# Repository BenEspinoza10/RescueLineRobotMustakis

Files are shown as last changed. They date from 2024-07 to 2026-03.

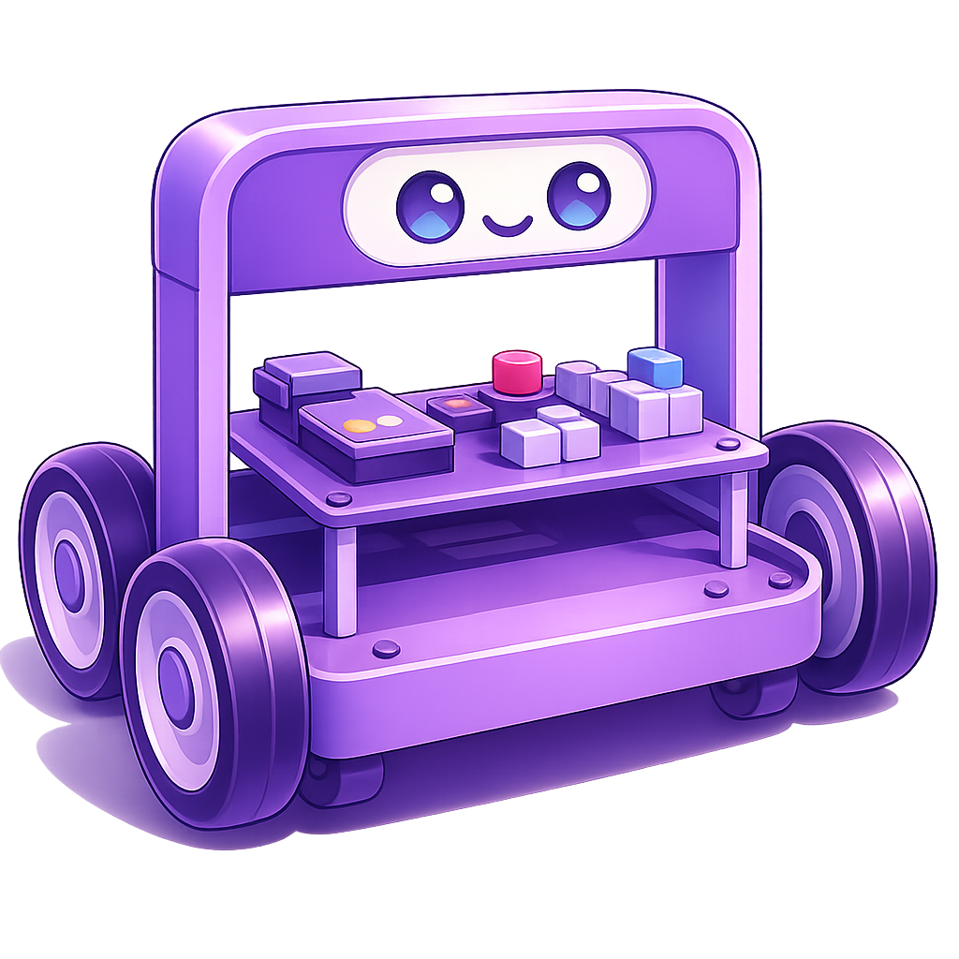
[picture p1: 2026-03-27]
misc/ChatGPT Image 10 mar 2026, 04_27_27 p.m..png

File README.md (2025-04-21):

# Club Robótica Linea Rescue Line
Este es el repositorio de la línea de robótica Rescue Line Aquí encontrás todo lo necesario para ejecutar las sesiones de manera exitosa.

## Sesiones
- Las presentaciones PPT por sesión se pueden encontrar en el siguiente link: [Presentaciones](https://docs.google.com/presentation/d/1HhJf0Knq2RezBDOXF99ei00qkOhWetyh1tN6ezIQvbw/edit?usp=drive_link)

## Archivos de construcción
En la carpeta archivos de construcción se pueden encontrar los modelos 3D, svg y el Gerber de Dynamis

En caso de ser necesario, dentro de la carpeta RescueLineRobot, se encuentra el proyecto original en KiCad. Este contienen los esquemáticos de los circuitos y el diseño de la pcb. 

## Errores y sugerencia

En caso de que se encuentren errores de contenido y/o cualquier otro problema relacionado a las sesiones, por favor añadirlo como una Issue al repositorio, de esta manera se queda registro de los cambios realizados historicamente para futuras referencias en un único lugar.

---
*Trabajo realizado por Benjamin Espinoza para el programa de Ciencia y Tecnología de la Fundación Mustakis, 2024*

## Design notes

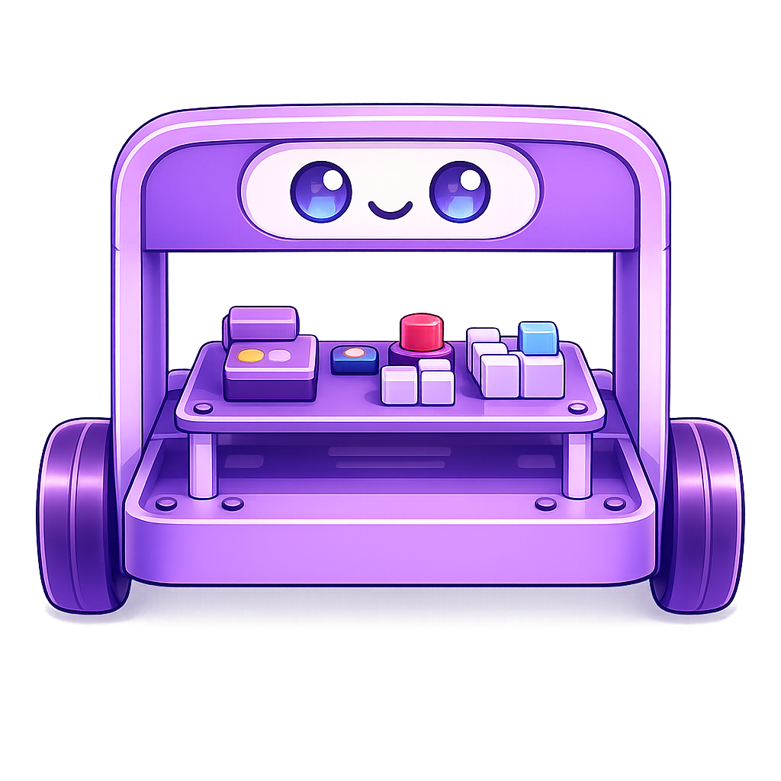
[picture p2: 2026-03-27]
misc/ChatGPT Image 10 mar 2026, 04_49_32 p.m..png

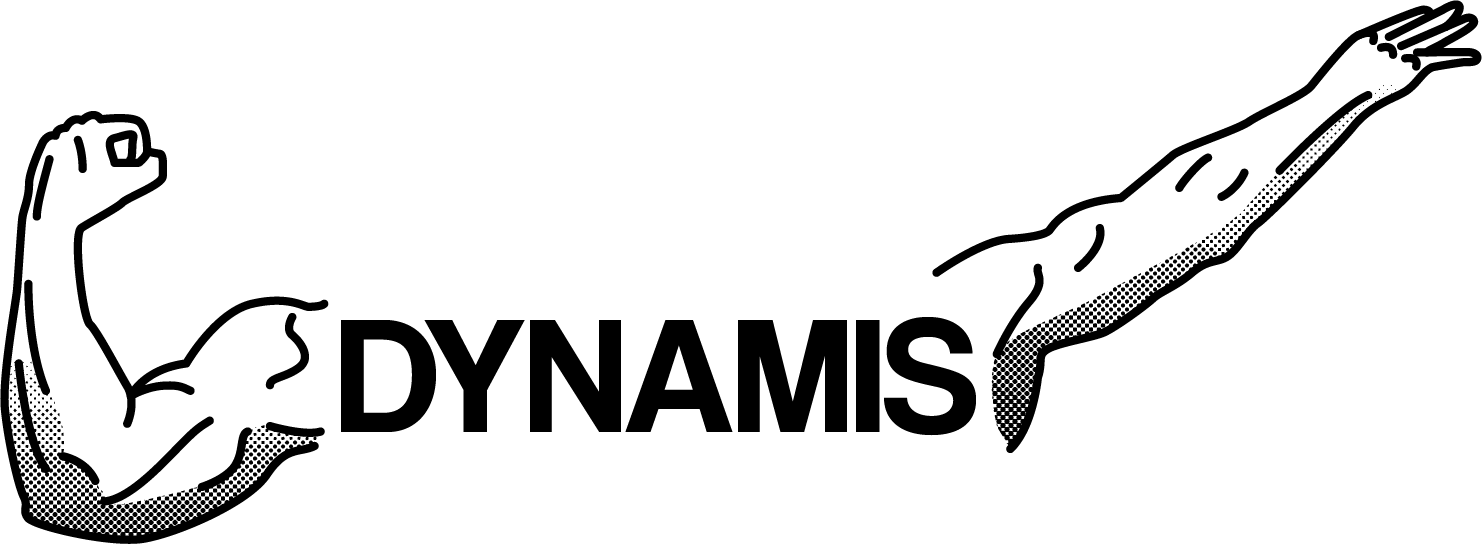
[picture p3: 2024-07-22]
misc/DyNaMis2.png

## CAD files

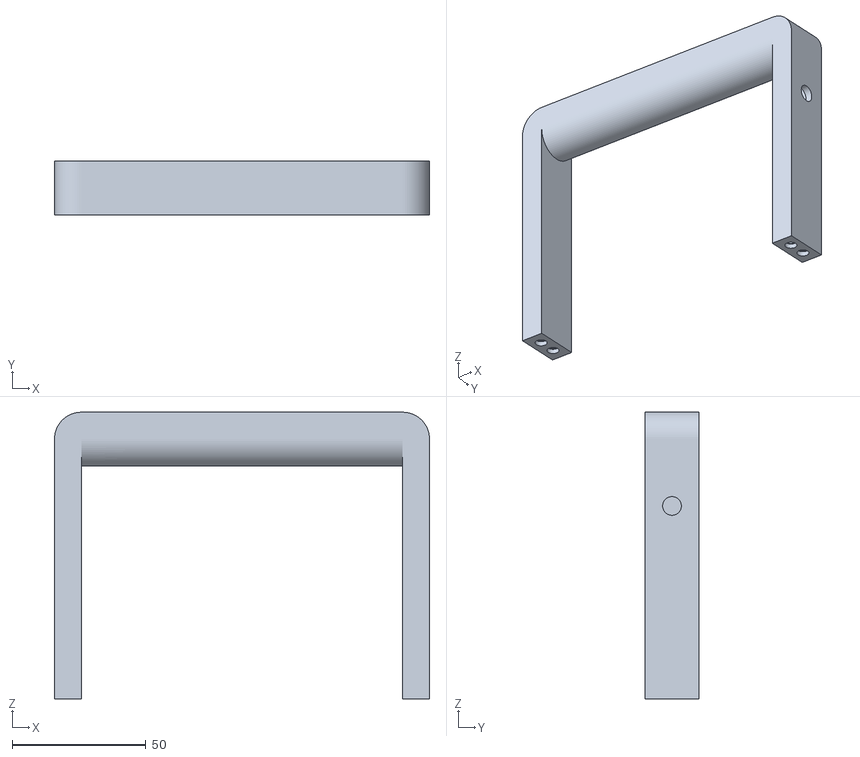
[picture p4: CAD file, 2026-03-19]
Archivos de construccion/V1.1/ManillaV2.stl
140.0 x 20.0 x 107.0

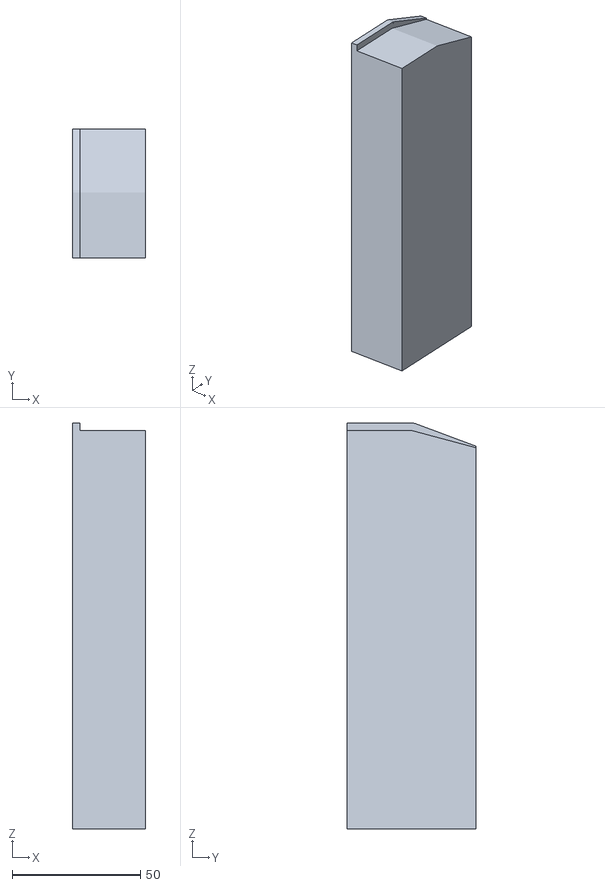
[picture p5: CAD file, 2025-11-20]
ArchivosRampa15grados60cm/PilarB.stl
28.4 x 50.1 x 158.0

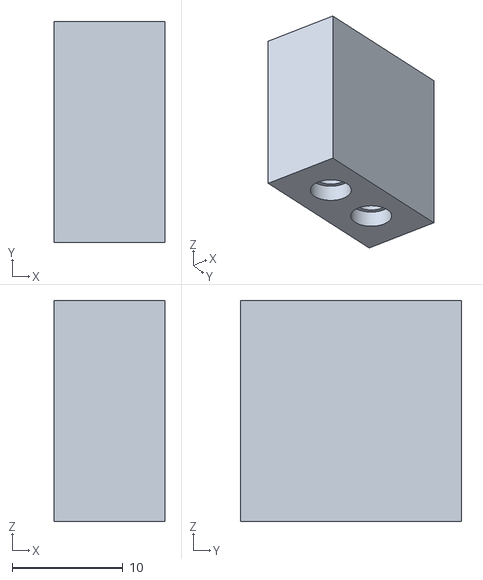
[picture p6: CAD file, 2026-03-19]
Archivos de construccion/V1.1/ManillaTEST.stl
10.0 x 20.0 x 20.0

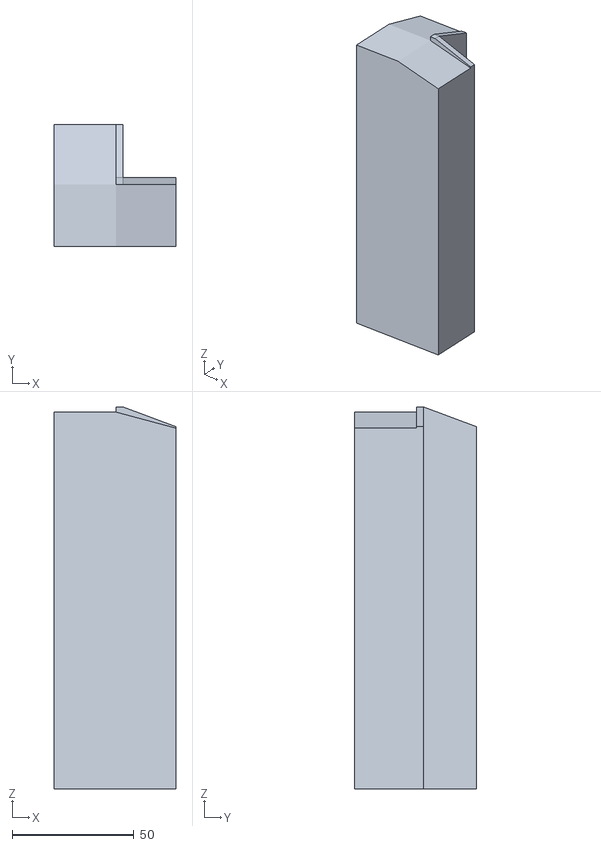
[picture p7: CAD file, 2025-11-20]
ArchivosRampa15grados60cm/PilarEsquinaInterna.stl
50.1 x 50.1 x 157.1

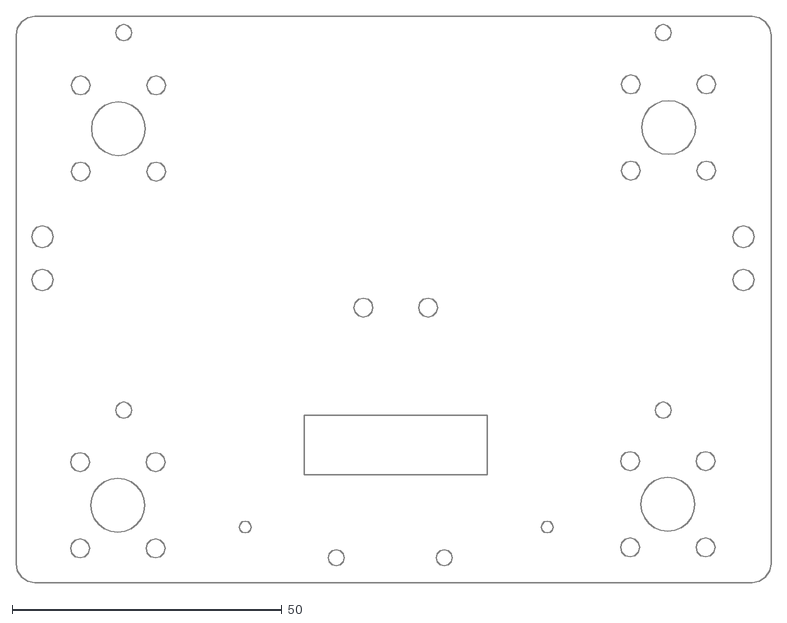
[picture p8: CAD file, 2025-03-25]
Archivos de construccion/V1.1/BaseDynamisV2.1.dxf
140.0 x 105.0

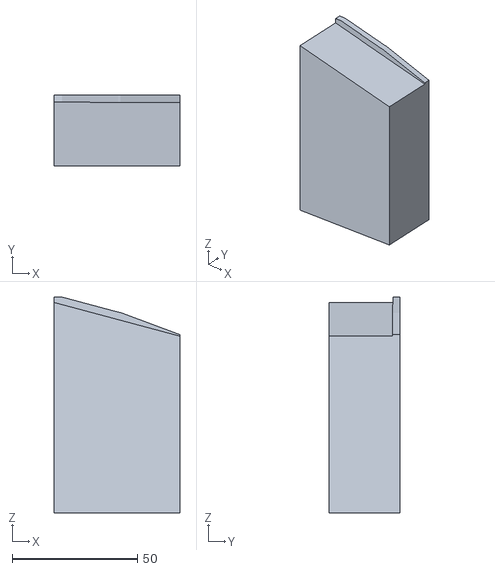
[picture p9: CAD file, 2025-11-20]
ArchivosRampa15grados60cm/Pilar IntermedioB.stl
50.1 x 28.4 x 86.1

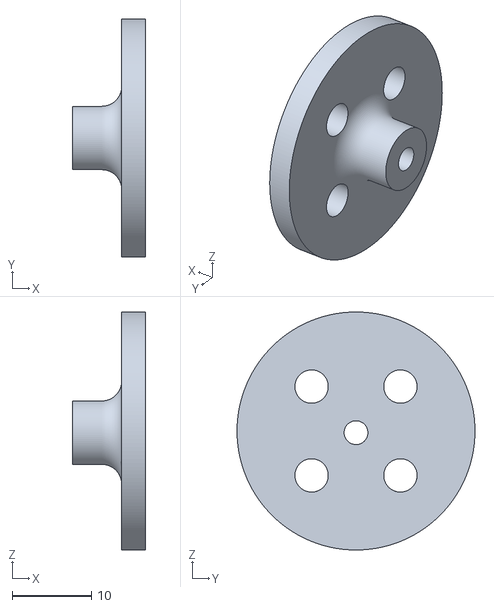
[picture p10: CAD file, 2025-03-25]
Archivos de construccion/V1.1/Enganche Rueda Rodamiento.stl
9.19 x 30.0 x 30.0

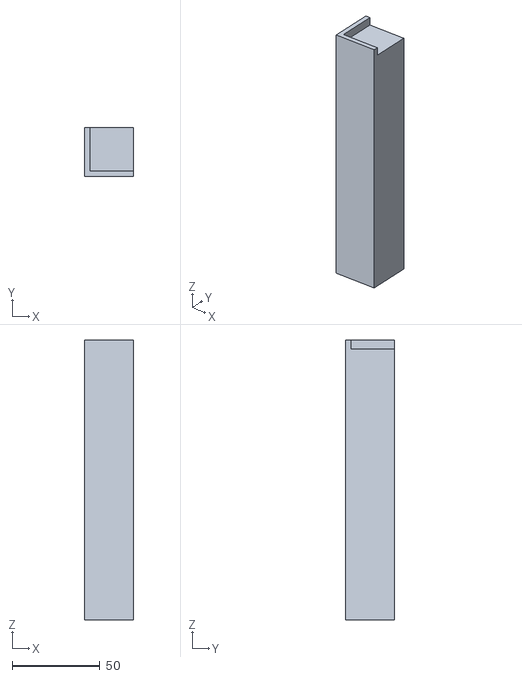
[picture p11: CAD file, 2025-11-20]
ArchivosRampa15grados60cm/PilarEsquinaExterna.stl
28.0 x 28.0 x 160.0

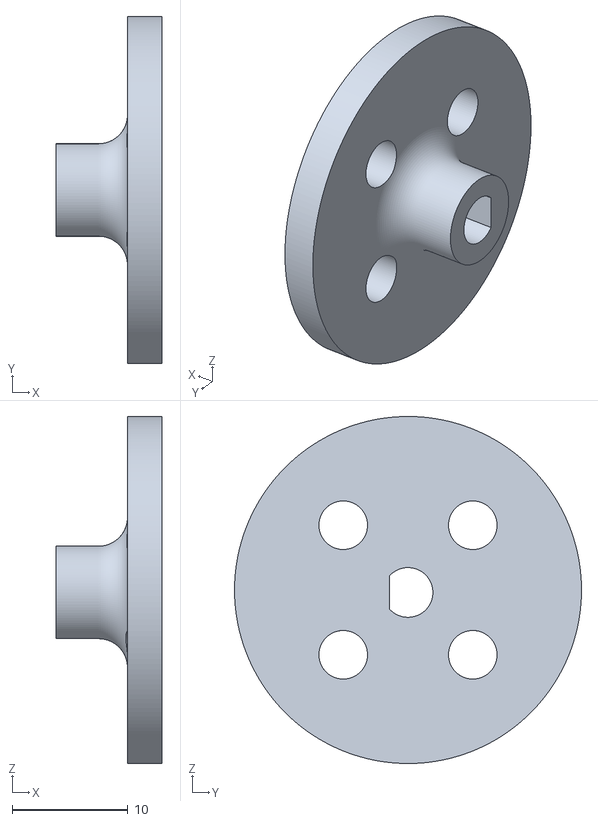
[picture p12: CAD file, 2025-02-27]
Archivos de construccion/V1.1/Enganche Rueda.stl
9.19 x 30.0 x 30.0

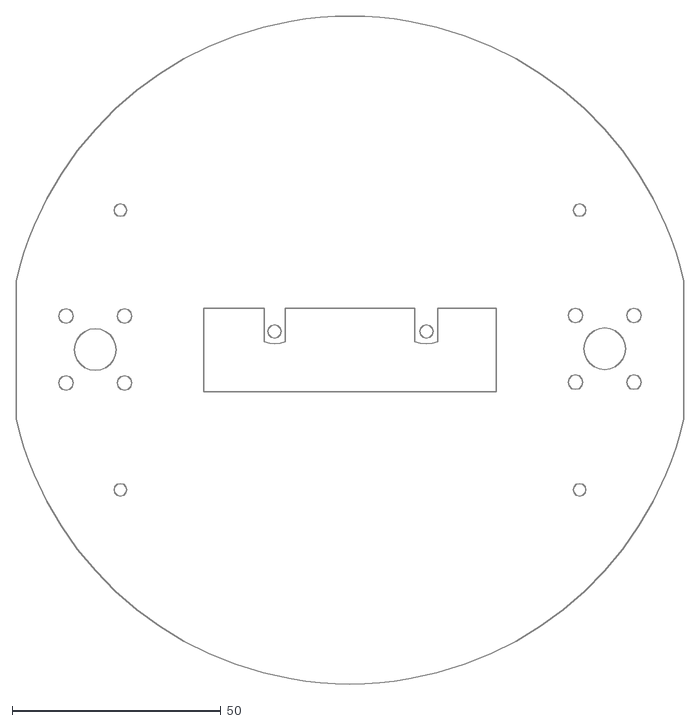
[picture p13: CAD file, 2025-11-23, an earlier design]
Archivos de construccion/V1/Robot Rescue Line/Base RescueLineRobot.dxf
160.0 x 160.0

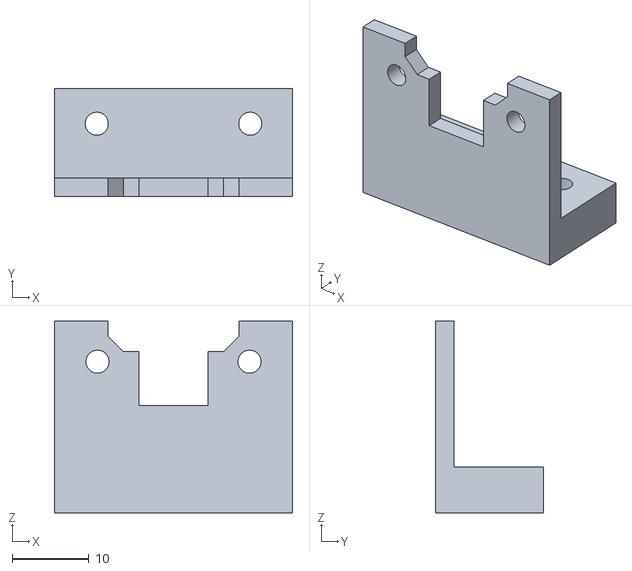
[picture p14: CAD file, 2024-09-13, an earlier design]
Archivos de construccion/V1/Soporte Láser Chico.stl
31.0 x 14.1 x 25.0

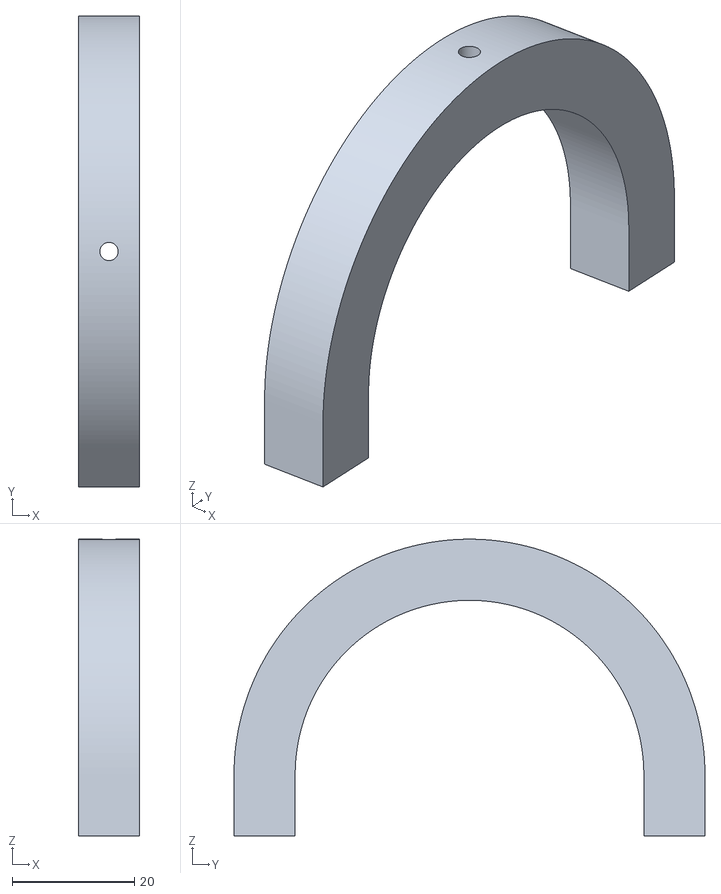
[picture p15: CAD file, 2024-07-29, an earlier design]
Archivos de construccion/V1/Robot Rescue Line/Base Handle.stl
10.0 x 77.0 x 48.5

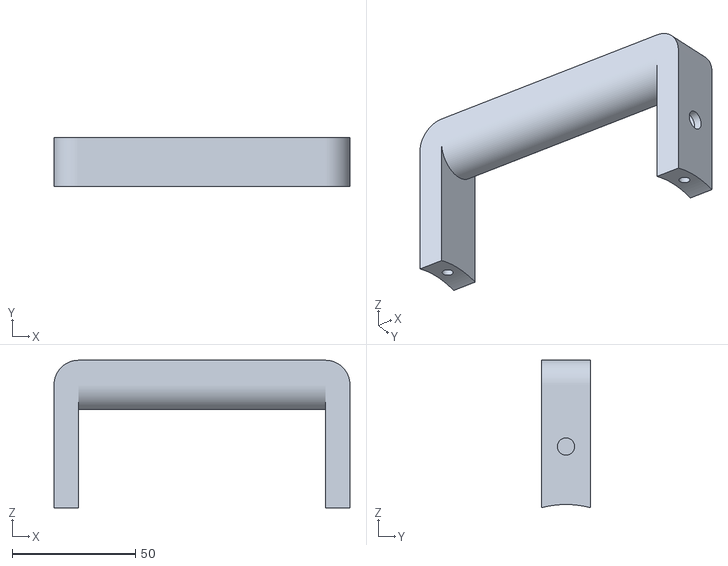
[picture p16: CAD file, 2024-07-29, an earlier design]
Archivos de construccion/V1/Robot Rescue Line/Handle.stl
120.0 x 20.0 x 59.8

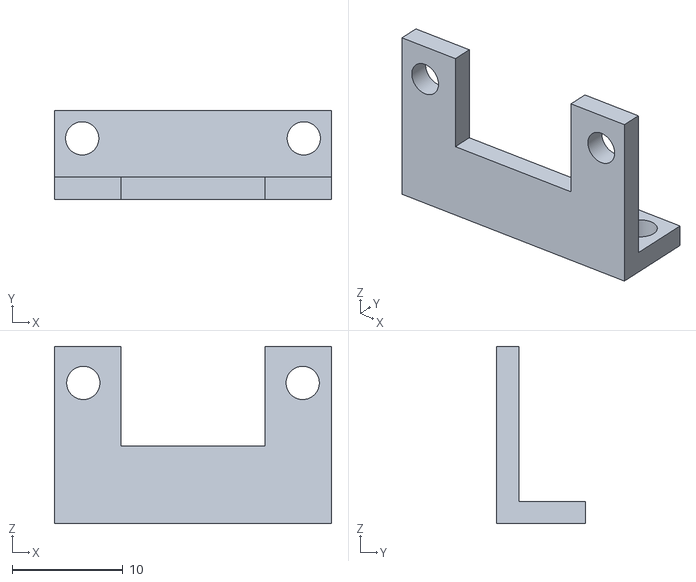
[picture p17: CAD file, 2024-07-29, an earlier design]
Archivos de construccion/V1/Robot Rescue Line/Soporte Láser.stl
25.0 x 8.00 x 16.0

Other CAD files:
ArchivosRampa15grados60cm/PilarA.stl
ArchivosRampa15grados60cm/Pilar IntermedioA.stl
Archivos de construccion/V1.1/Manilla.stl
Archivos de construccion/V1.1/BaseDynamisV2.dxf
Archivos de construccion/V1.1/RescueLineRobot.f3z
Fusion360/RescueLineRobot.f3z

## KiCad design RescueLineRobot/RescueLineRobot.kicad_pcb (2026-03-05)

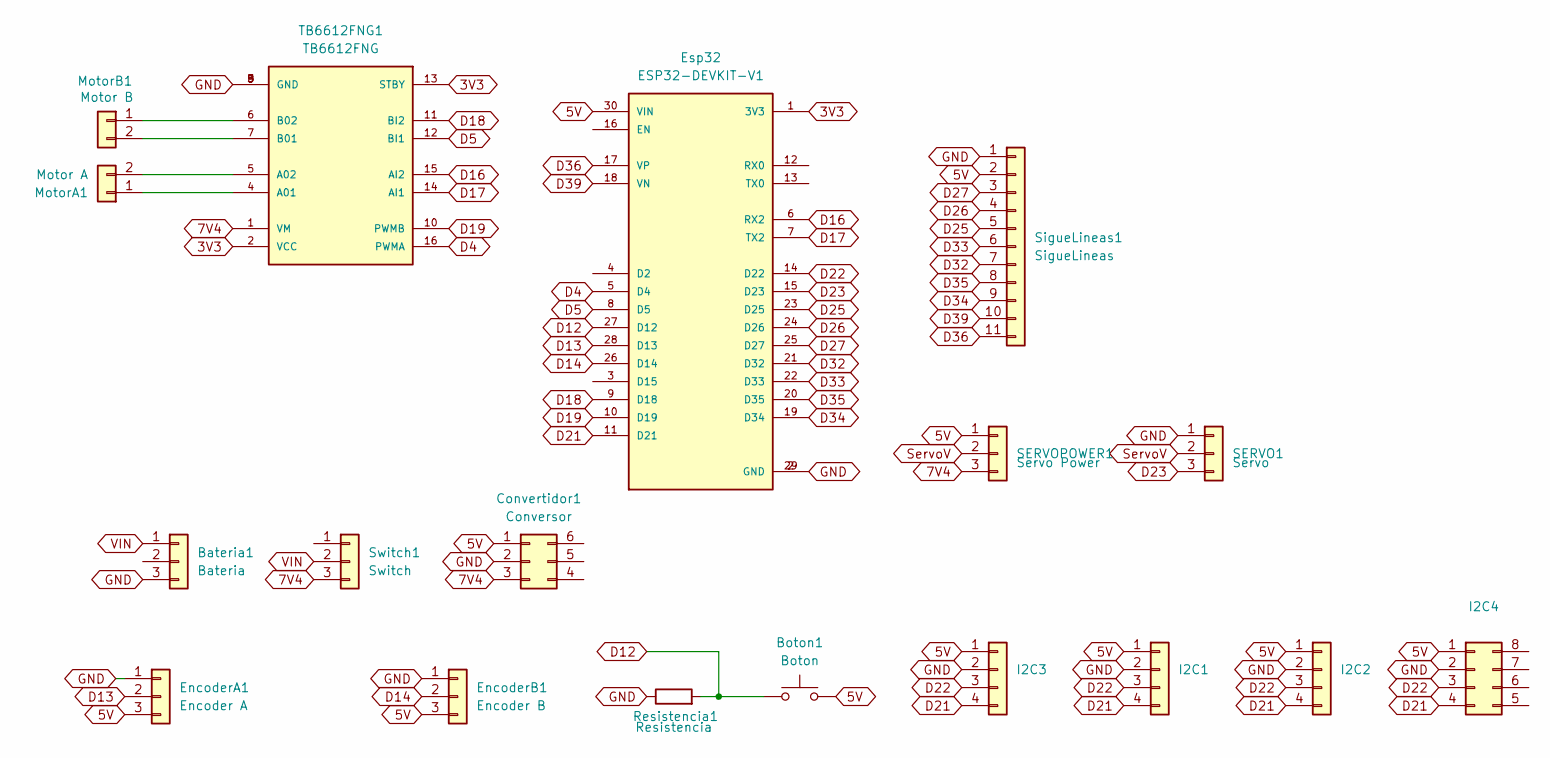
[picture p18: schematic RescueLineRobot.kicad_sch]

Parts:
Bateria1: Bateria; JST_XH_B3B-XH-A_1x03_P2.50mm_Vertical
Boton1: Boton; SW_PUSH-12mm
Convertidor1: Conversor; PinHeader_2x03_P2.54mm_Vertical
EncoderA1: Encoder A; JST_XA_B03B-XASK-1_1x03_P2.50mm_Vertical
EncoderB1: Encoder B; JST_XA_B03B-XASK-1_1x03_P2.50mm_Vertical
Esp32: ESP32-DEVKIT-V1; MODULE_ESP32_DEVKIT_V1; PARTREV N/A
I2C1, I2C2, I2C3, I2C4: JST_XH_B4B-XH-A_1x04_P2.50mm_Vertical
MotorA1: Motor A; JST_XH_B2B-XH-A_1x02_P2.50mm_Vertical
MotorB1: Motor B; JST_XH_B2B-XH-A_1x02_P2.50mm_Vertical
Resistencia1: Resistencia; R_Axial_DIN0617_L17.0mm_D6.0mm_P25.40mm_Horizontal
SERVO1: Servo; JST_XH_B3B-XH-A_1x03_P2.50mm_Vertical
SERVOPOWER1: Servo Power; PinHeader_1x03_P2.54mm_Vertical
SigueLineas1: SigueLineas; JST_XH_B11B-XH-A_1x11_P2.50mm_Vertical
Switch1: Switch; JST_XH_B3B-XH-A_1x03_P2.50mm_Vertical
TB6612FNG1: TB6612FNG; MODULE_ROB-14450; PARTREV 11-13-17

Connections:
3V3: Esp32.1 (3V3), TB6612FNG1.2 (VCC), TB6612FNG1.13 (STBY)
5V: Boton1.2, Convertidor1.1, EncoderA1.3, EncoderB1.3, Esp32.30 (VIN), I2C1.1, I2C2.1, I2C3.1, I2C4.1, SERVOPOWER1.1, SigueLineas1.2
7V4: Convertidor1.3, SERVOPOWER1.3, Switch1.3, TB6612FNG1.1 (VM)
D4: Esp32.5 (D4), TB6612FNG1.16 (PWMA)
D5: Esp32.8 (D5), TB6612FNG1.12 (BI1)
D12: Boton1.1, Esp32.27 (D12), Resistencia1.2
D13: EncoderA1.2, Esp32.28 (D13)
D14: EncoderB1.2, Esp32.26 (D14)
D16: Esp32.6 (RX2), TB6612FNG1.15 (AI2)
D17: Esp32.7 (TX2), TB6612FNG1.14 (AI1)
D18: Esp32.9 (D18), TB6612FNG1.11 (BI2)
D19: Esp32.10 (D19), TB6612FNG1.10 (PWMB)
D21: Esp32.11 (D21), I2C1.4, I2C2.4, I2C3.4, I2C4.4
D22: Esp32.14 (D22), I2C1.3, I2C2.3, I2C3.3, I2C4.3
D23: Esp32.15 (D23), SERVO1.3
D25: Esp32.23 (D25), SigueLineas1.5
D26: Esp32.24 (D26), SigueLineas1.4
D27: Esp32.25 (D27), SigueLineas1.3
D32: Esp32.21 (D32), SigueLineas1.7
D33: Esp32.22 (D33), SigueLineas1.6
D34: Esp32.19 (D34), SigueLineas1.9
D35: Esp32.20 (D35), SigueLineas1.8
D36: Esp32.17 (VP), SigueLineas1.11
D39: Esp32.18 (VN), SigueLineas1.10
GND: Bateria1.3, Convertidor1.2, EncoderA1.1, EncoderB1.1, Esp32.2 (GND), Esp32.29 (GND), I2C1.2, I2C2.2, I2C3.2, I2C4.2, Resistencia1.1, SERVO1.1, SigueLineas1.1, TB6612FNG1.3 (GND), TB6612FNG1.8 (GND), TB6612FNG1.9 (GND)
unnamed: MotorA1.1, TB6612FNG1.4 (A01)
unnamed: MotorA1.2, TB6612FNG1.5 (A02)
unnamed: MotorB1.1, TB6612FNG1.6 (B02)
unnamed: MotorB1.2, TB6612FNG1.7 (B01)
ServoV: SERVO1.2, SERVOPOWER1.2
VIN: Bateria1.1, Switch1.2

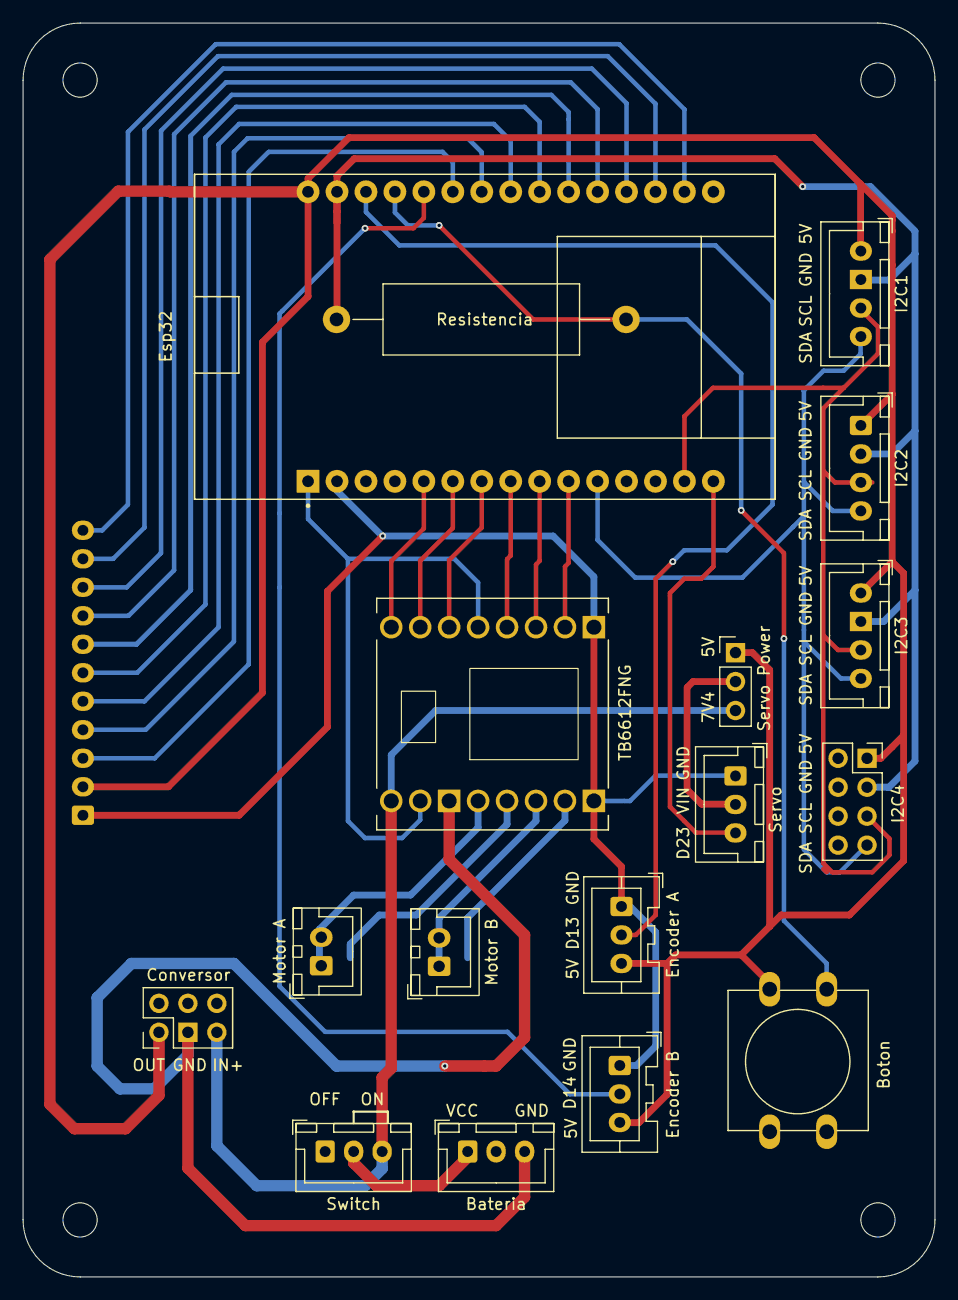
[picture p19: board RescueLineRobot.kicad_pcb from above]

Board: 2 copper layers, 80.0 x 110.0 mm, 18 parts (1 on the bottom side), 31 nets.

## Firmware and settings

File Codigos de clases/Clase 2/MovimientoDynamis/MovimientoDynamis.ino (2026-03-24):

//Se incluyen los pines
#include "Pines.h"

//Se define la frecuencia y resolución
//Se puede jugar con la frecuencie entre 5000 y 8000, no vale la pena tocar la resolución
const int freq = 5000;
const int resolution = 8;


void setup() {
  // Se inicializa los motores
  inicializarMotores();
  //Se espera a que se presione el botón para empezar
  while (digitalRead(BOTON) == 0) {
  }
}

void loop() {
  //Una serie de movimientos para probar las diferentes capacidades de la funcion
  Motor(150,150);
  delay(1000);
  Motor(-150,150);
  delay(1000);
  Motor(0,0);
  delay(1000);
  Motor(150,-150);
  delay(1000);
}

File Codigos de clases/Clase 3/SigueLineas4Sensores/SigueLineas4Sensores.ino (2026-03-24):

#include "Pines.h"
//Librería para el sensor IR
#include <QTRSensors.h>

const int freq = 5000;
const int resolution = 8;

//Se crea el objeto del qtr
QTRSensors qtr;

//Se crea el arreglo para almacenar las lectura
const uint8_t SensorCount = 8;
uint16_t sensorValues[SensorCount];

//Se definen umbrales para cada sensor (valores arbitrarios, en la practica se debe ajustar)
int umbrales[SensorCount] = {3000,3000,3000,3000,3000,3000,3000,3000};

void setup() {
  inicializarMotores();
  inicializarSensores();
  while (digitalRead(BOTON) == 0) {
  }
}

void loop() {
  //Se actualiza la lectura del sensor
  qtr.read(sensorValues);
  //Se hace un siguelíneas simple con máquina de estados
  //B,B,B,B
  if (sensorValues[2] < umbrales[2] and sensorValues[3] < umbrales[3] and sensorValues[4] < umbrales[4] and sensorValues[5] < umbrales[5]){
    Motor(0,0);
  //B,N,N,B
  } else if (sensorValues[2] < umbrales[2] and sensorValues[3] >= umbrales[3] and sensorValues[4] >= umbrales[4] and sensorValues[5] < umbrales[5]){
    Motor(50,50);
  //N,N,B,B
  } else if (sensorValues[2] >= umbrales[2] and sensorValues[3] >= umbrales[3] and sensorValues[4] < umbrales[4] and sensorValues[5] < umbrales[5]){
    Motor(50,100);
  //B,B,N,N
  } else if (sensorValues[2] < umbrales[2] and sensorValues[3] < umbrales[3] and sensorValues[4] >= umbrales[4] and sensorValues[5] >= umbrales[5]){
    Motor(100,50);
  }
}

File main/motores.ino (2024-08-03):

#include"definiciones.h"
void setupMotores(){
  //configuracion motores
  pinMode(BIN2  , OUTPUT);
  pinMode(BIN1  , OUTPUT);
  ledcSetup(1, freq, resolution);
  ledcAttachPin(PWMB, 1);
  pinMode(AIN1  , OUTPUT);
  pinMode(AIN2  , OUTPUT);
  ledcSetup(0, freq, resolution);
  ledcAttachPin(PWMA, 0);
}


void Motoriz(int value) {
  if ( value >= 0 ) {
    digitalWrite(BIN1, LOW);
    digitalWrite(BIN2, HIGH);
  } else {
    digitalWrite(BIN1, HIGH);
    digitalWrite(BIN2, LOW);
    value *= -1;
  }
  ledcWrite(0, value);
}
// Función accionamiento motor derecho
void Motorde(int value) {
  if ( value >= 0 ) {
    digitalWrite(AIN1, HIGH);
    digitalWrite(AIN2, LOW);
  } else {
    digitalWrite(AIN1, LOW);
    digitalWrite(AIN2, HIGH);
    value *= -1;
  }
  ledcWrite(1, value);
}

//Accionamiento de motores
void mover(int left, int righ) {
  Motoriz(left);
  Motorde(righ);
}

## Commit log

2024-03-12 Sensor y motores
    Se ajustó cableado de puente h y sensores para que quede mas simple la pcb, el sensor funciona con un código sucio xd
2024-03-12 Motores funcionan :D
    [RescueLineRobot.kicad_pcb, RescueLineRobot.kicad_sch]
2024-03-13 Actualizacion de pcb
    Ahora la pcb está más limpia y con serigrafía
    Pendientes:
    -2 Sensores RGB
    -1 Botón pulsador
    -2 Encoders para los motores (aun no se si cuadraticos o no)
    -1 Puerto para servo (maybe con selector de voltaje)
    [RescueLineRobot.kicad_pcb, RescueLineRobot.kicad_sch]
2024-03-13 Boton y encoders
    [RescueLineRobot.kicad_pcb, RescueLineRobot.kicad_sch]
2024-03-14 Estamos Casi
    Están todas las rutas hechas, todos los puertos necesarios, sólo falta nombrar al robot y poner gráficas
    [RescueLineRobot.kicad_pcb, RescueLineRobot.kicad_sch]
2024-03-14 logo update
    [RescueLineRobot.kicad_pcb]
2024-03-18 Dynamis a nacido
    Estamos listos señores!!!
    [RescueLineRobot.kicad_pcb, RescueLineRobot.kicad_sch]
2024-04-06 Arreglo de dirección
2024-04-09 Create pruebaBoton.ino
    Se creo el archivo para probar el boton
2024-04-11 ni idea que sea esto xd
    [RescueLineRobot.kicad_pcb]
2024-07-29 Arreglo sensores
2024-07-29 preparacion final
    [Base Handle.stl, Handle.stl, Soporte Láser.stl]
2024-08-03 Motores fix
    Se arreglaron los headers de los motores para que sean consistentes en todos los robots
    [motores.ino, pruebaMotores.ino, pruebaPID.ino]
2024-09-13 No se que es esto xd
    [Soporte Láser Chico.stl]
2025-02-27 Nueva versión
    [Base Handle.stl, Enganche Rueda.stl, Handle.stl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]
2025-03-25 Orden github
    [BaseDynamisV2.1.dxf, Enganche Rueda Rodamiento.stl, Manilla.stl]
2025-11-20 nueva rampa
    [Pilar IntermedioA.stl, Pilar IntermedioB.stl, PilarA.stl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]
2025-11-23 Encontré esto y mejor tener backup
    [Base Handle.stl, Base RescueLineRobot.dxf, Handle.stl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]
2026-02-25 Dynamis V2
    - Sólo 4 i2c en la placa
    - Cambiar serigrafía de los motores hacia el lado superior
    - Agrandar puenteo para el voltaje del servo
    - Rotar conector de QTR hacia el lado más largo de la placa
    [RescueLineRobot.kicad_pcb, RescueLineRobot.kicad_sch]
2026-02-26 Arreglo regulador de voltaje
    [RescueLineRobot.kicad_pcb, RescueLineRobot.kicad_sch]
2026-02-27 Cambio giroscopio
    Se cambio el sistema de acople del giroscopio para que sea igual al del conversor de voltaje
    [RescueLineRobot.kicad_pcb, RescueLineRobot.kicad_sch]
2026-02-27 Creacion Gerber v2
    [BaseDynamisV2.1.dxf, BaseDynamisV2.dxf, Enganche Rueda Rodamiento.stl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]
2026-02-27 Fix GerberV2
    [RescueLineRobot-B_Cu.gbr, RescueLineRobot-B_Mask.gbr, RescueLineRobot-B_Paste.gbr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]
2026-03-05 Last pcb changes
    Arreglo de puerto i2c para el giroscopio
    [RescueLineRobot-B_Cu.gbr, RescueLineRobot-B_Mask.gbr, RescueLineRobot-B_Paste.gbr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]
2026-03-19 Fix manilla
    Se hizo mas profundo el hoyo para los insertos de metal
    [ManillaTEST.stl, ManillaV2.stl]
2026-03-19 Little fix manillas
    [ManillaTEST.stl, ManillaV2.stl]
2026-04-01 Nuevo codigo de pruebas generalizados solo para sensores
2026-04-02 Unificacion motor
2026-04-03 Update motores
    Ahora todo los motores funcionan bien
2026-05-20 Archivo fusion
    Se añadió el ultimo archivo de fusion360 del modelo del robot completo
    [RescueLineRobot.f3z]
2026-06-22 Ideas segundo semestre
    Hay que hacer sufrir a los NNJ
